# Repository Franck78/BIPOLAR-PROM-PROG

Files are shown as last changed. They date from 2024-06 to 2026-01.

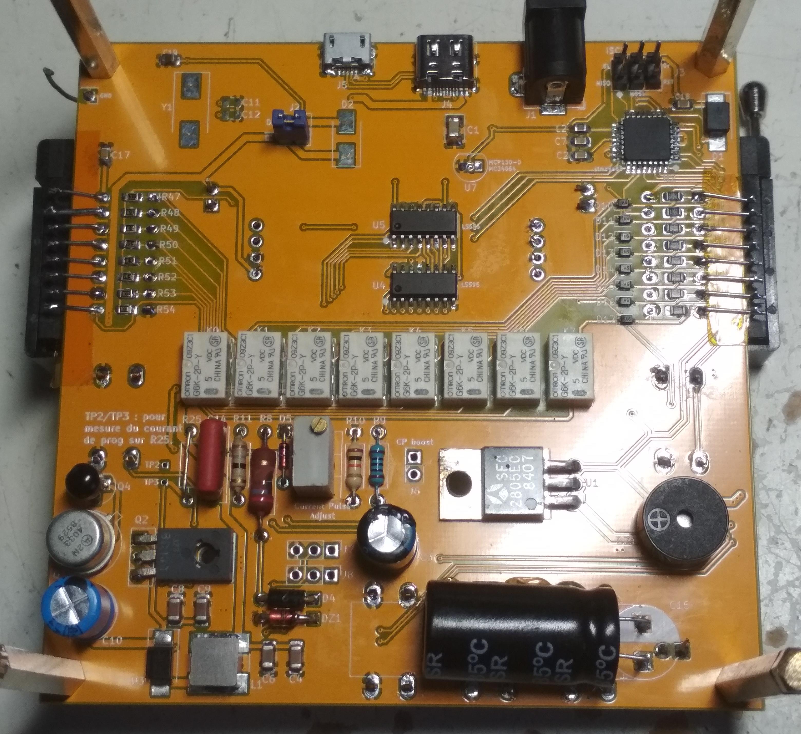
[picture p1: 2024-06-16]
images/assembled-bottom.jpg

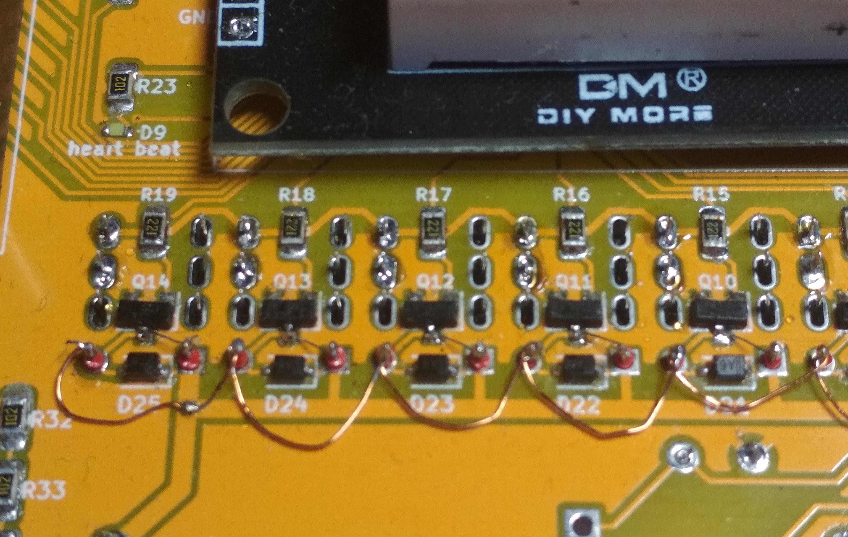
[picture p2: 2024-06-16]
images/relay-fix.jpg

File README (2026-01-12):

BIPOLAR PROM PROGRAMMER

Another one in the arena !

This one is based on the Atmega to repeat easily programming a PROM.

It reads the source from a master PROM
It writes what is memory to a virgin PROM

Values can be modified on the fly if needed. That is similar to
the 'manual' programmers found everywhere.

A default PROM file is used when 'Read' is pressed and nothing is in the socket.
The goal of this project was programming a dozen of PROMS, so it makes sense for me
to have that default loaded.

TODO: use the internal eeprom of the mega to store/retrieve PROM files. 
TODO: use the serial port to send files (remember entering 32 values is not really
time consumming, so this is luxury.

I'm using KiCad 5. It works for me until I upgrade my old laptop. Don't send request
about version.

The code is occupying 85% of the AtMega88. What is code consumming is
the human interface ! Moving to atMega328 is possible.
TODO: remove DigitalRead DigitalWrite functions (code consumming I think)

version 1.0 of the pcb was really botched to work. Version v1.1 fixed all that
but I made a mistake with the G6K relay footprint. In this repository, this is
fixed.
But I still have 4 usable PCB from JLCPCB. Pin 1 and 8 of each relay need to be
swapped. It can be done by soldering the relay on the other side. I choose to
put them on the correct side and inserted insulation on the two pins then solder
correctly.

Another thing is the ZIF socket. AliExpress 3M Textool is shit reproduction.
I ordered Aries reproduction, much better but pin space is 'wide'. But they
can be used. They can also be opened (a good hammer and strong pin) to 
reinsert each contact to get the narrow version.

HOW TO used

Insert the PROM to copy in the 'Read' socket, press 'R' button

The CRC32 is displayed until another key is pressed.
If all zero is read, then the default PROM file is used. 
This is signaled by a double beep.

Use + / - to display each address and content.
Press V to edit a value (with + / -). Display starts
blinking.
Press V again to accept the updated value.

When everything is OK, insert a virgin PROM and press 'W'
Program will fuse bit 0 on each 32 position, then bit 1
then ... This limits the relays actuating.

Read of the 'Write' socket is done for comparison. When
green LED lits, it is a success.
If not, retry. Only failed bits will be refused.

The serial port reports outputs what the programmer is doing.
Is is not required to have a terminal nut it helps.

I had in mind some flexibility for the current programming 
(the pulse). I did not explore possibilities of burning
other brand.
I have tested the programmer with

N82S23AN (K8608) from Signetics.
with minor modification and new software
TBP18S030N

I have 4 spare PCB to sell (instead of asking 5 new ones to JLPCB).
I'm not doing that for the money of course but avoid filling my bin.

About the PCB
I wanted sockets and button covered properly in a box. This why
all 'big' components are on the bottom side. 
Need to make a box now ;)

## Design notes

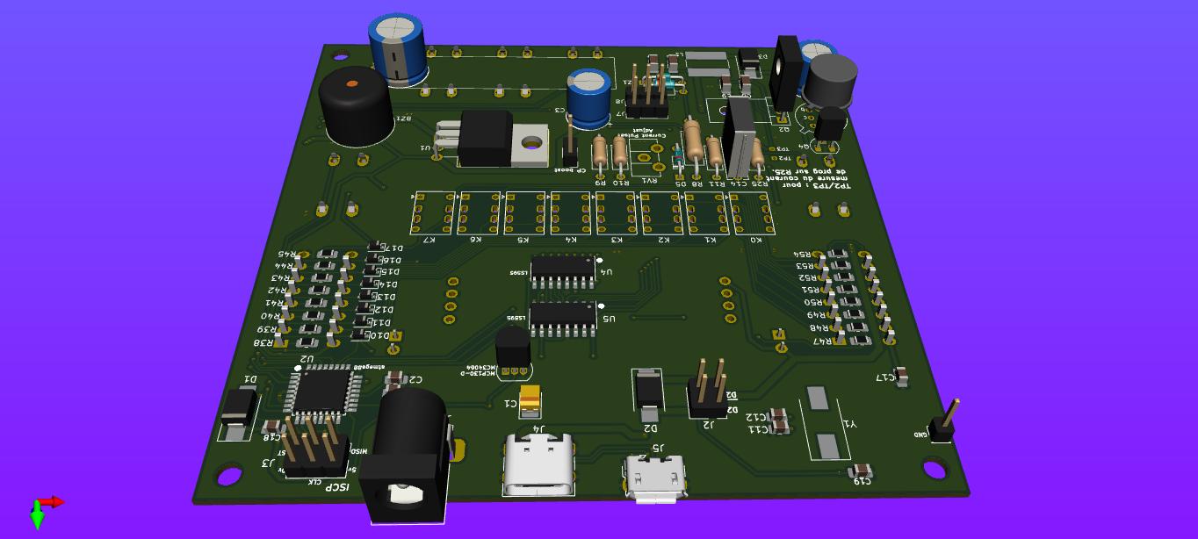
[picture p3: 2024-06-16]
images/kicad-prom-prog-bottom.jpg

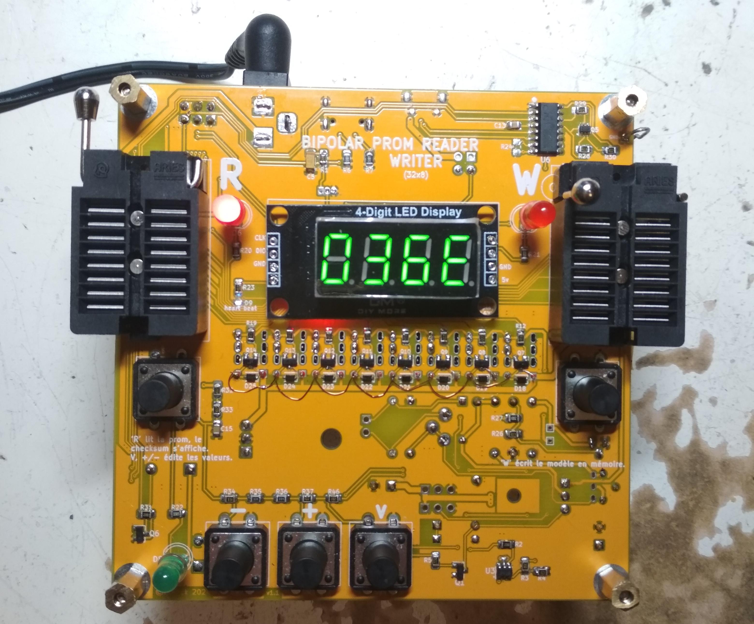
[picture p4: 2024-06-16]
images/running.jpg

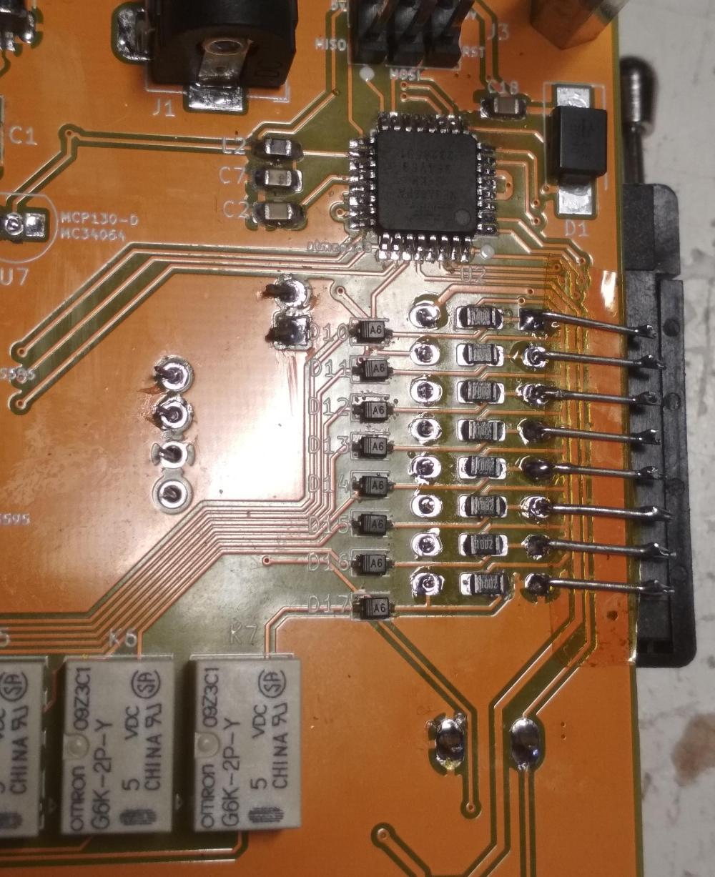
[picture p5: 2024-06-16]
images/using-aries-zif.jpg

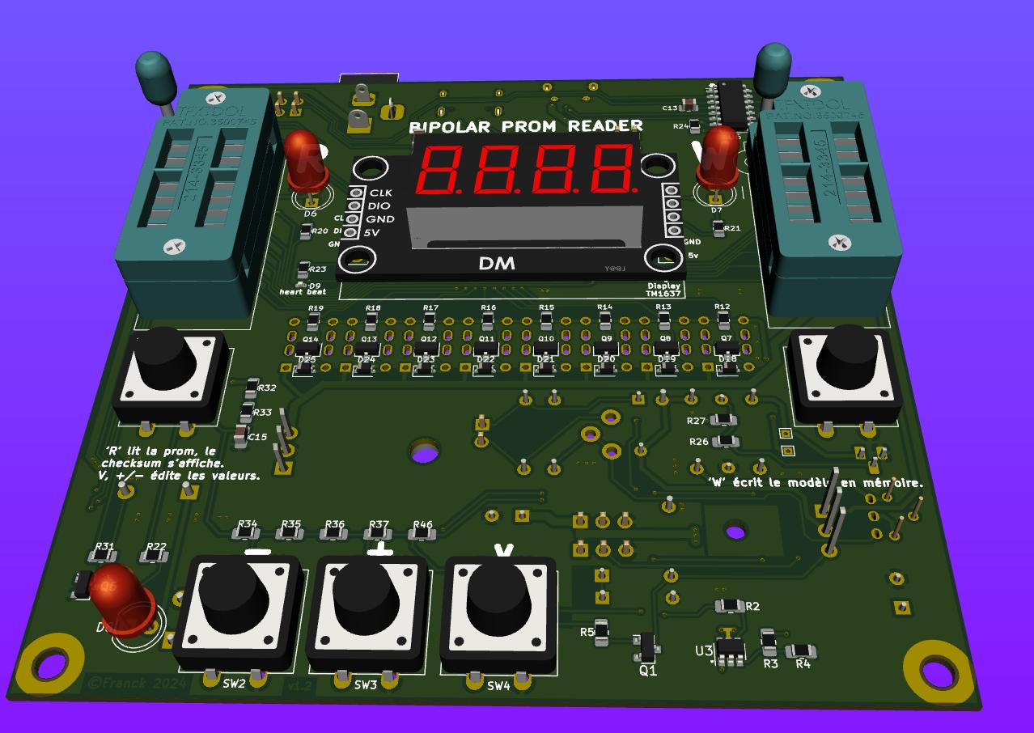
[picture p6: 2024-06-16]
images/kicad-prom-prog-top.jpg

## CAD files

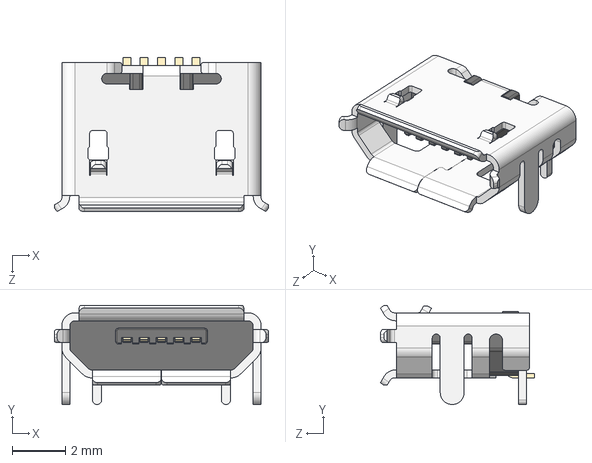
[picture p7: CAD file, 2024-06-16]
Micro USB-B Female 5Pin SMD.STEP
8.05 x 3.73 x 5.80 mm

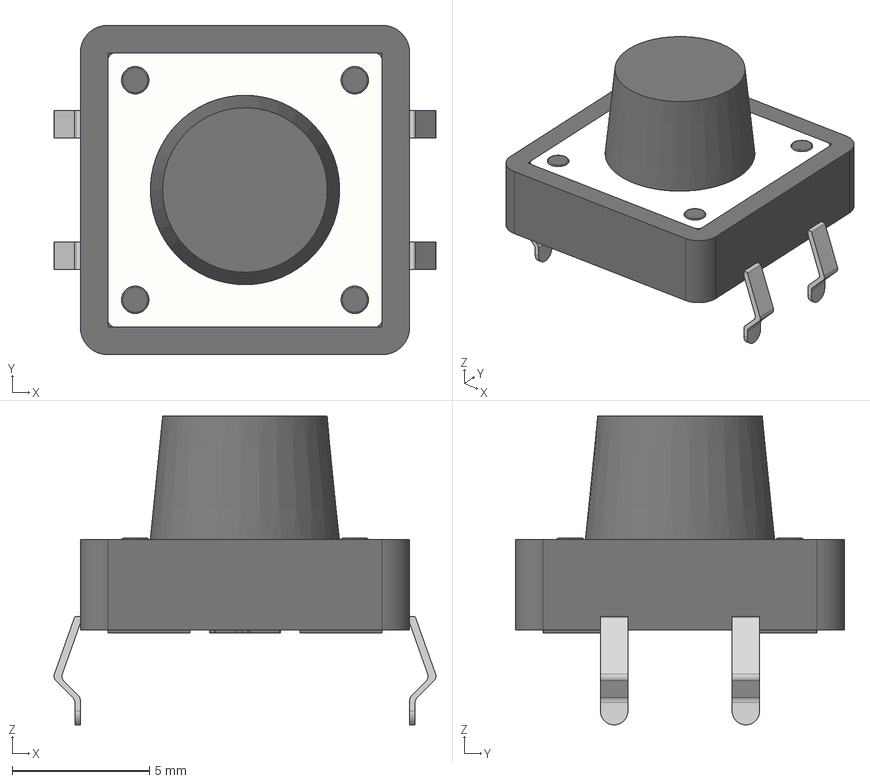
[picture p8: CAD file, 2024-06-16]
12mm x 12mm Tactile switch Button.step
13.9 x 12.0 x 11.2 mm
External Case
Steel Plate
Push Button

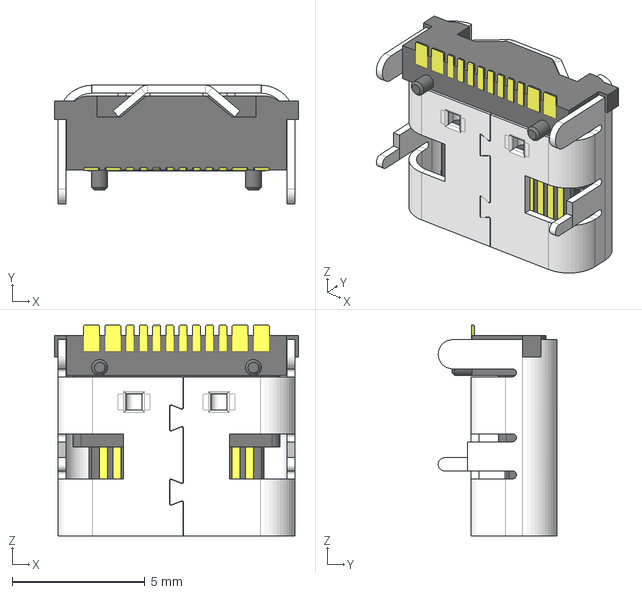
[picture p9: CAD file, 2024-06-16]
USB_type_C_smd_12p.stp
9.20 x 4.47 x 7.95 mm

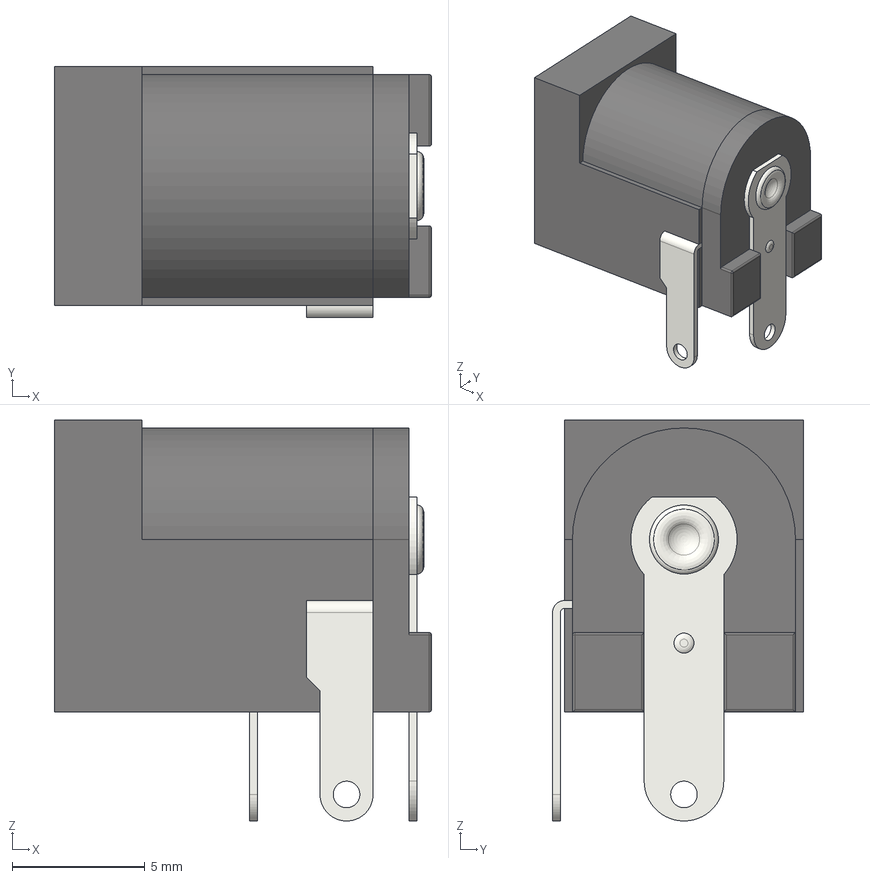
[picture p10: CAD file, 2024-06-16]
DC_Power_Jack_PCB_Mounted_2.1mm.step
14.2 x 9.45 x 15.1 mm
Plastic_Body_1of2
Plastic_Body_2of2
PIN_01
PIN_03
PIN_02
Boner

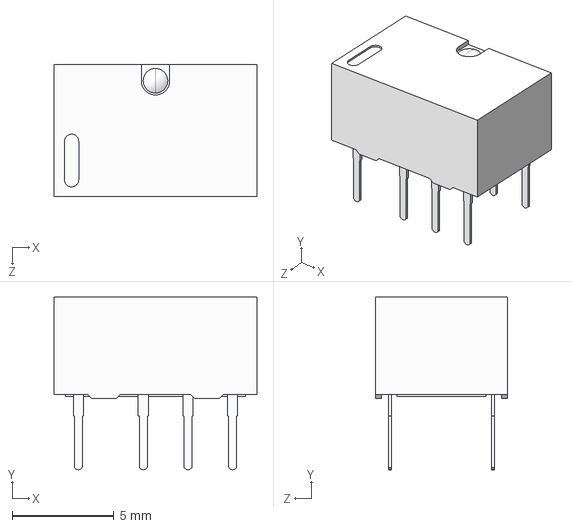
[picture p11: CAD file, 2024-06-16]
G6K-2P-Y-DC5.stp
10.0 x 8.50 x 6.50 mm

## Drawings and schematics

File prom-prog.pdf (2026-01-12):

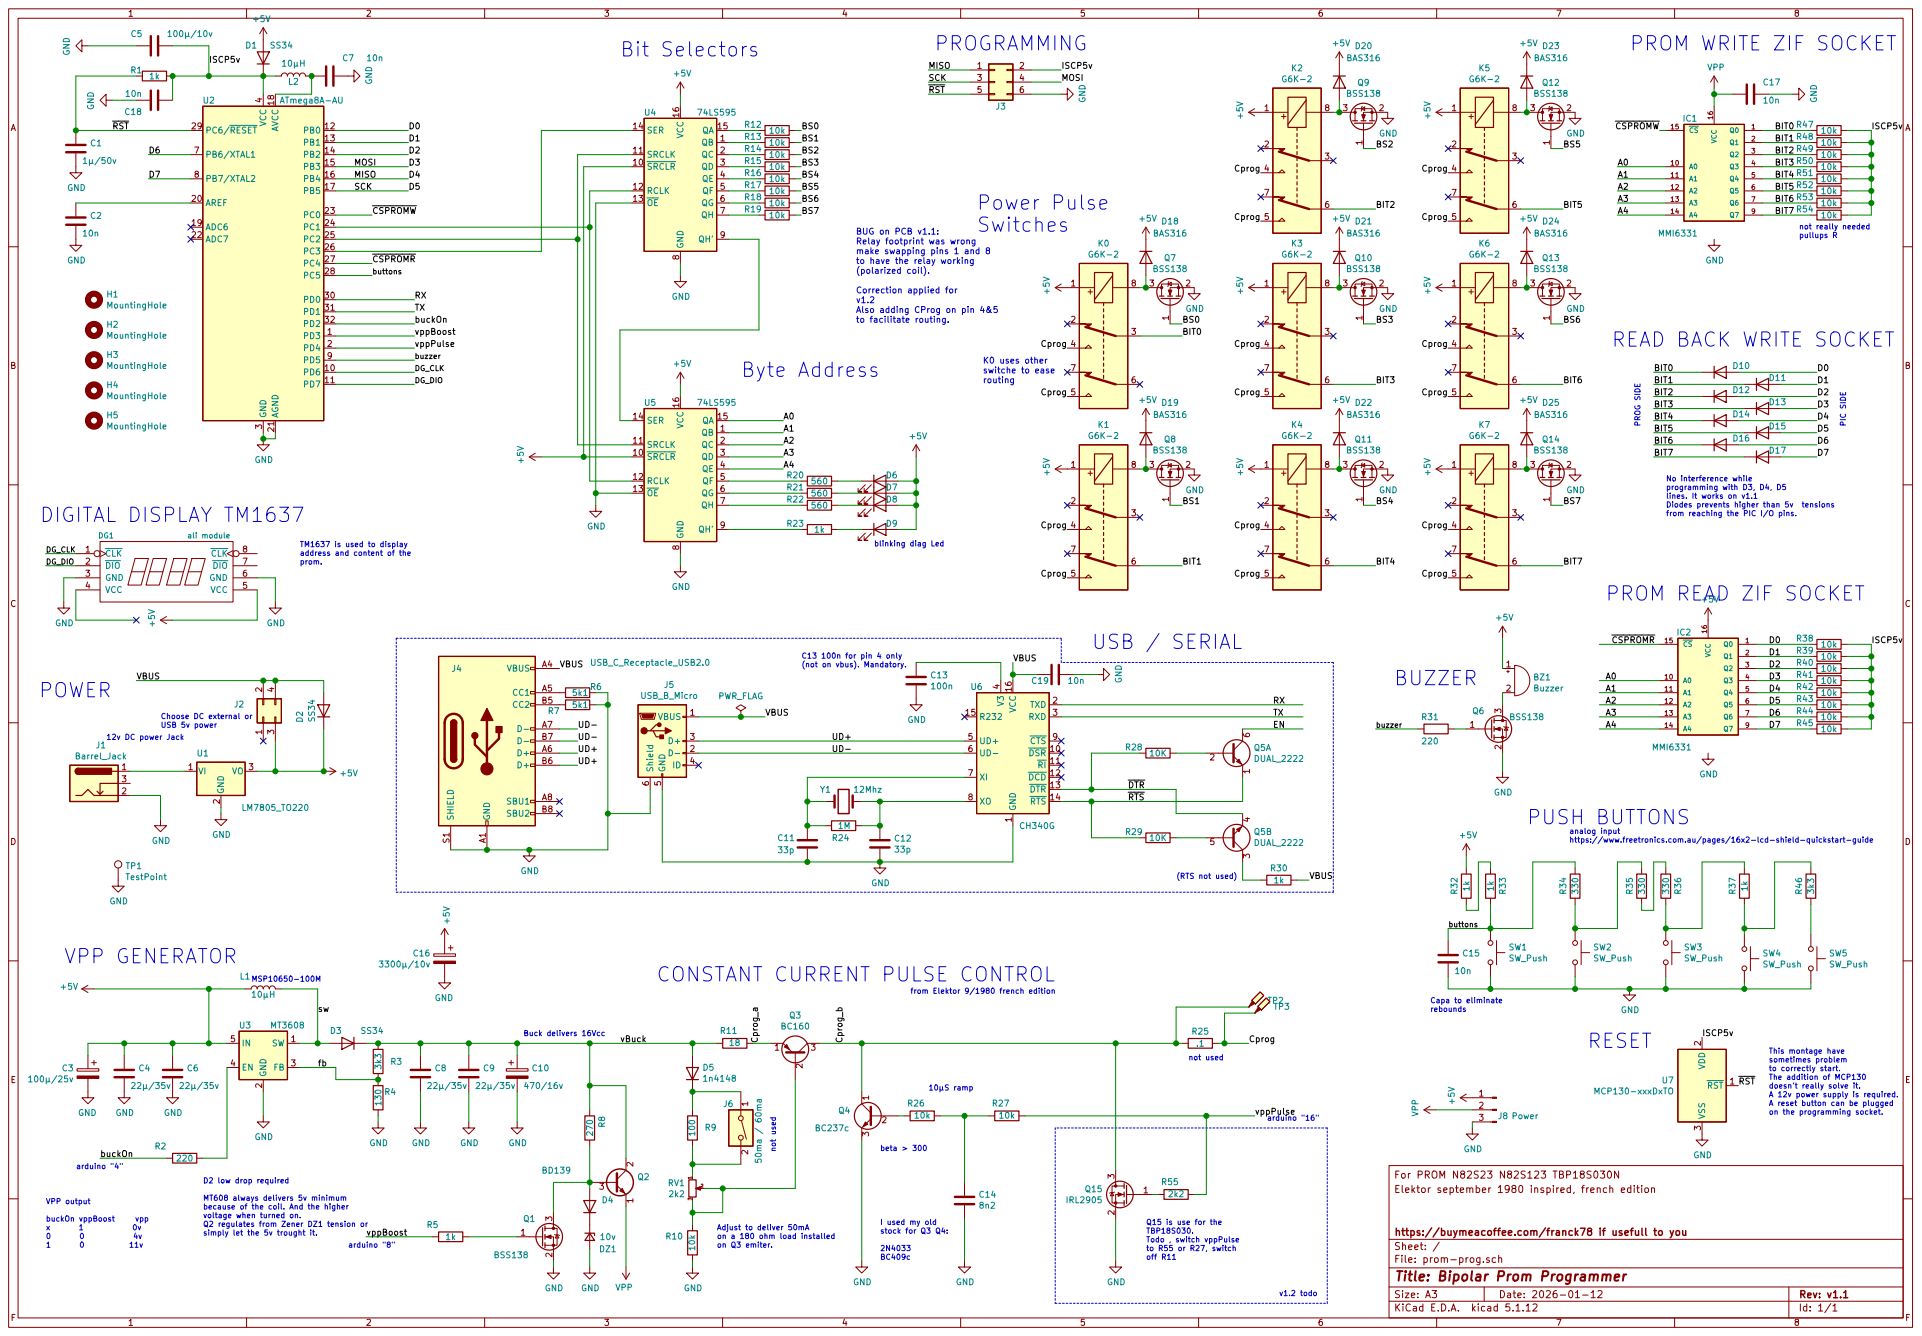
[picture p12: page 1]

(RTS not used) PROGRAMMING
Cprog SCK

PROM WRITE ZIF SOCKET

routing BUG on PCB v1.1: Relay footprint was wrong

make swapping pins 1 and 8
to have the relay working
(polarized coil).

Correction applied for v1.2 Also adding CProg on pin 4&5

READ BACK WRITE SOCKET

K0 uses other switche to ease

programming with D3, D4, D5
lines. It works on v1.1 Diodes prevents higher than 5v tensions

from reaching the PIC I/O pins. USB / SERIAL

TM1637 is used to display address and content of the

blinking diag Led
(not on vbus). Mandatory. not used

1 DSR 10 RI 11 DCD 12 DTR 13 RTS 14 R232 15 VCC 16 TXD 2 RXD 3 V3

4 UD+ 5 UD- 6 XI 7 XO 8 CTS 9 U6 CH340G VDD

analog input https://www.freetronics.com.au/pages/16x2-lcd-shield-quickstart-guide PUSH BUTTONS

rebounds CONSTANT CURRENT PULSE CONTROL

sometimes problem
to correctly start. The addition of MCP130

doesn't really solve it. A 12v power supply is required. A reset button can be plugged

on the programming socket. arduino "4"

D2 low drop required MT608 always delivers 5v minimum

Elektor september 1980 inspired, french edition For PROM N82S23 N82S123 TBP18S030N

because of the coil. And the higher voltage when turned on. Q2 regulates from Zener DZ1 tension or simply let the 5v trought it.

Adjust to deliver 50mA
on a 180 ohm load installed
on Q3 emiter.

Q15 is use for the TBP18S030. Todo , switch vppPulse

File: prom-prog.sch Sheet: / https://buymeacoffee.com/franck78 if usefull to you

Id: 1/1 Title: Bipolar Prom Programmer

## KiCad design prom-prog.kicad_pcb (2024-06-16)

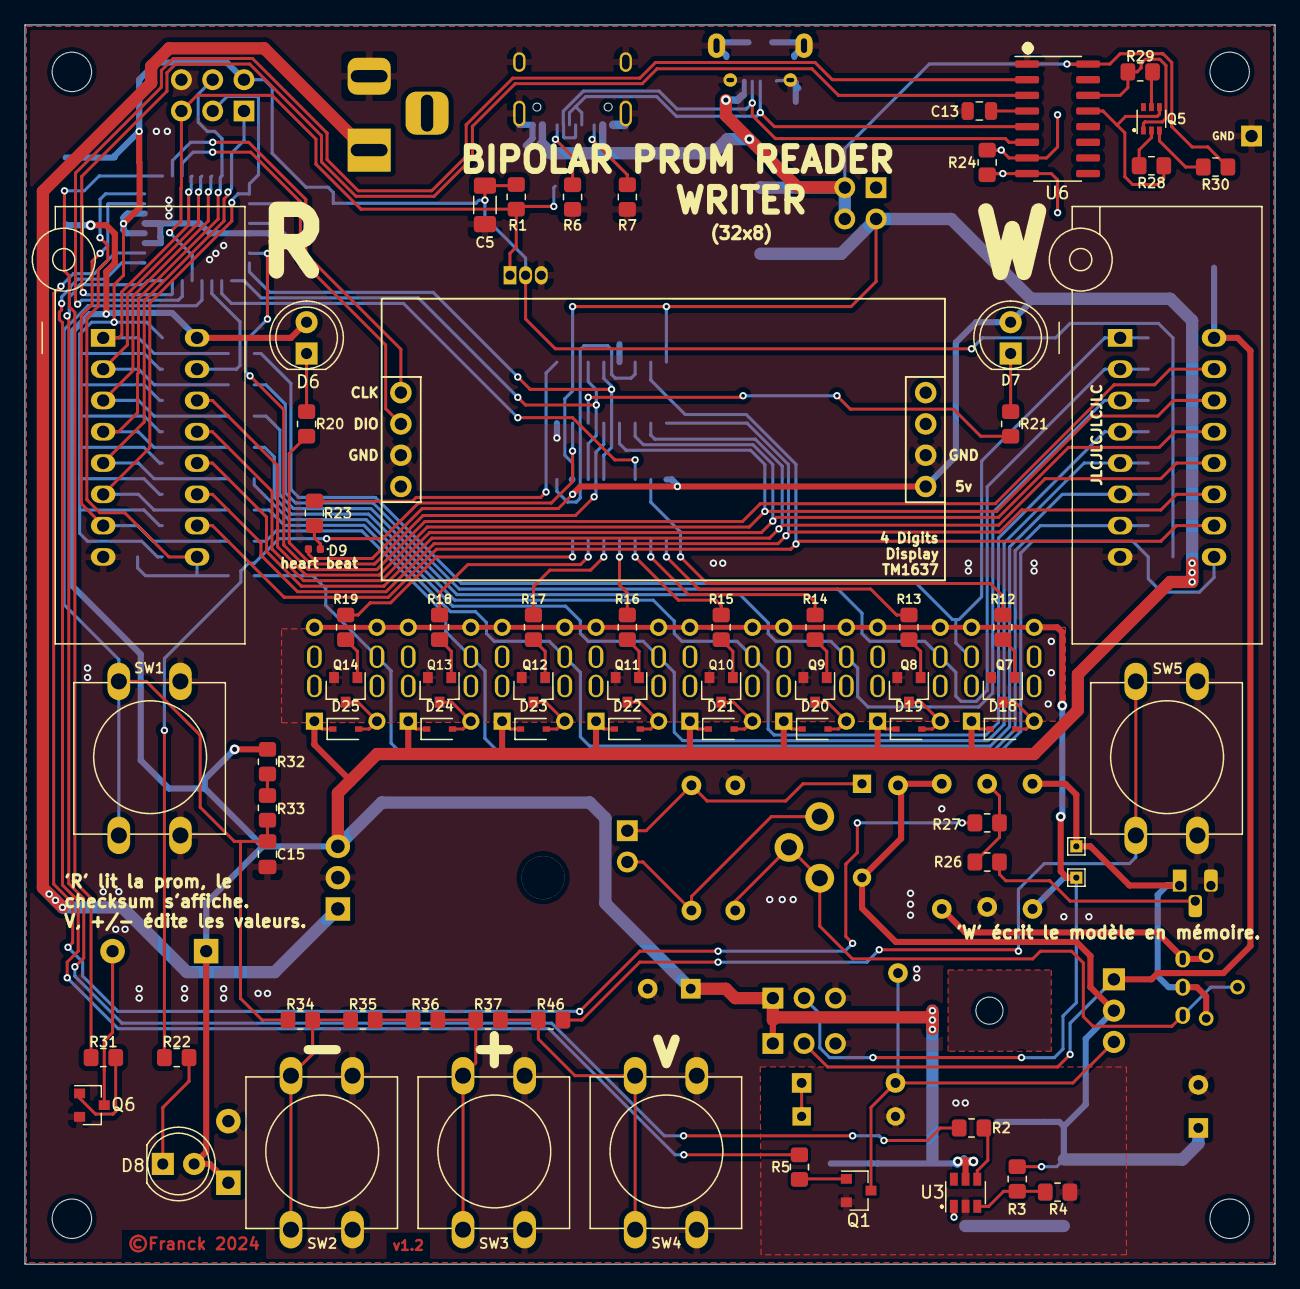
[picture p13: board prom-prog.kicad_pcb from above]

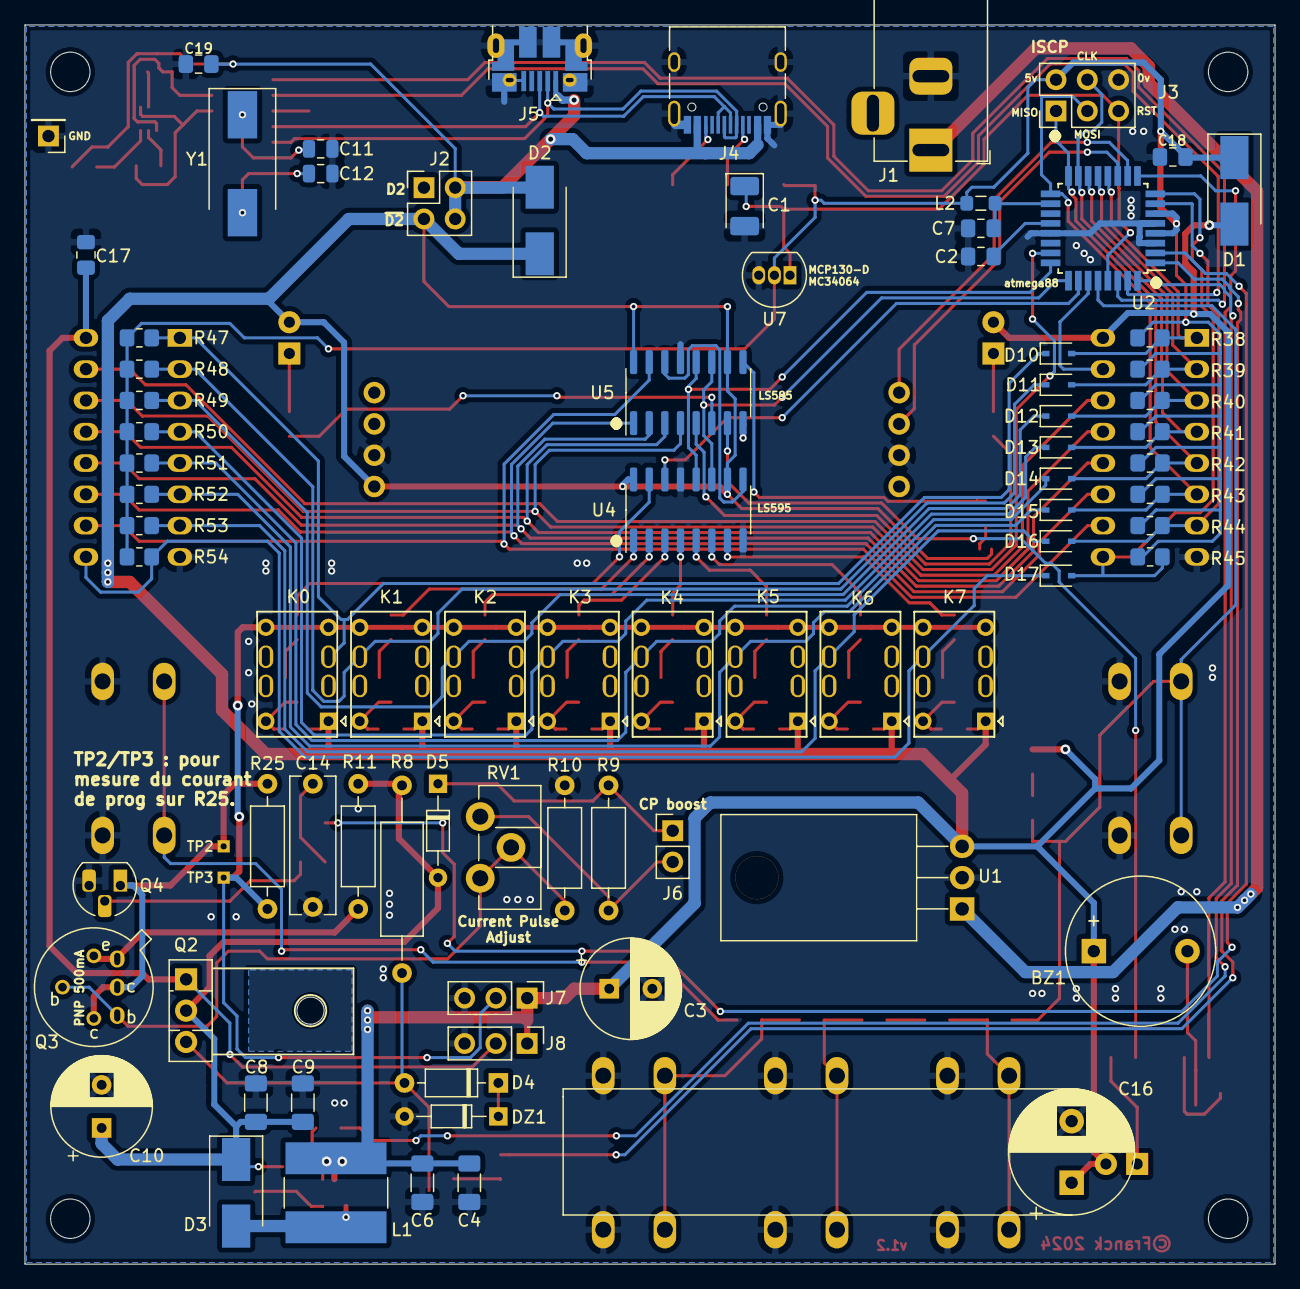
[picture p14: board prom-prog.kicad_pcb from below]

Board: 2 copper layers, 101.5 x 100.6 mm, 157 parts (81 on the bottom side), 112 nets.

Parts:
BZ1: Buzzer; Buzzer_12x9.5RM7.6
C1: 1µ/50v; CP_EIA-3528-21_Kemet-B_Pad1.50x2.35mm_HandSolder
C2, C7, C15, C17, C18, C19: 10n; C_0805_2012Metric_Pad1.18x1.45mm_HandSolder
C3: 100µ/25v; CP_Radial_D8.0mm_P3.50mm
C4, C6, C8, C9: 22µ/35v; C_1206_3216Metric_Pad1.33x1.80mm_HandSolder
C5: 100µ/10v; C_1206_3216Metric_Pad1.33x1.80mm_HandSolder
C10: 470/16v; CP_Radial_D8.0mm_P3.50mm
C11, C12: 33p; C_0805_2012Metric
C13: 100n; C_0805_2012Metric
C14: 8n2; C_Rect_L11.0mm_W3.5mm_P10.00mm_MKT
C16: 3300µ/10v; CP_Radial_D10.0mm_P5.00mm
D1, D2, D3: SS34; D_SMB_Handsoldering
D4: 1n4004; D_DO-35_SOD27_P7.62mm_Horizontal
D5: 1n4148; D_DO-34_SOD68_P7.62mm_Horizontal
D6, D7, D8: LED; LED_D5.0mm
D9: LED; LED_0402_1005Metric
D10, D11, D12, D13, D14, D15, D16, D17: 1n4148; D_SOD-323
D18, D19, D20, D21, D22, D23, D24, D25: BAS316; D_SOD-323
DG1: ali module; 4DigitSerial
DZ1: 10v; D_DO-34_SOD68_P7.62mm_Horizontal
H1, H2, H3, H4: MountingHole; MountingHole_3.2mm_M3
H5: MountingHole; MountingHole_2.2mm_M2_DIN965
IC1, IC2: MMI6331; DIP_Socket-16_W4.3_W5.08_W7.62_W10.16_W10.9_3M_216-3340-00-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
J1: Barrel_Jack; BarrelJack_Horizontal
J2: Conn_02x02_Odd_Even; PinHeader_2x02_P2.54mm_Vertical
J3: Conn_02x03_Odd_Even; PinHeader_2x03_P2.54mm_Vertical
J4: USB_C_Receptacle_USB2.0; USB_C_Receptacle_HRO_TYPE-C-31-M-12
J5: USB_B_Micro; USB_Micro-B_AliExpress
J6: 50ma / 60ma; PinHeader_1x02_P2.54mm_Vertical
J7, J8: Power; PinHeader_1x03_P2.54mm_Vertical
K0, K1, K2, K3, K4, K5, K6, K7: G6K-2; G6K-2P-YZ
L1: 10µH; L_Bourns-SRN8040_8x8.15mm
L2: 10µH; L_0805_2012Metric_Pad1.05x1.20mm_HandSolder
Q1, Q6, Q7, Q8, Q9, Q10, Q11, Q12, Q13, Q14: BSS138; SOT-23
Q2: BD139; TO-126-3_Vertical
Q3: BC160; TO-39-3
Q4: BC237; TO-92_HandSolder
Q5: DUAL_2222; SOT-363_SC-70-6
R1, R5, R23, R30, R32, R33, R37: 1k; R_0805_2012Metric_Pad1.20x1.40mm_HandSolder
R2, R31: 220; R_0805_2012Metric_Pad1.20x1.40mm_HandSolder
R3, R46: 3k3; R_0805_2012Metric_Pad1.20x1.40mm_HandSolder
R4: 130; R_0805_2012Metric_Pad1.20x1.40mm_HandSolder
R6, R7: 5k1; R_0805_2012Metric_Pad1.20x1.40mm_HandSolder
R8: 270; R_Axial_DIN0309_L9.0mm_D3.2mm_P15.24mm_Horizontal
R9: 100; R_Axial_DIN0207_L6.3mm_D2.5mm_P10.16mm_Horizontal
R10: 10k; R_Axial_DIN0207_L6.3mm_D2.5mm_P10.16mm_Horizontal
R11: 18; R_Axial_DIN0207_L6.3mm_D2.5mm_P10.16mm_Horizontal
R12, R13, R14, R15, R16, R17, R18, R19, R26, R27, R38, R39, R40, R41, R42, R43, R44, R45, R47, R48, R49, R50, R51, R52, R53, R54: 10k; R_0805_2012Metric_Pad1.20x1.40mm_HandSolder
R20, R21, R22: 560; R_0805_2012Metric_Pad1.20x1.40mm_HandSolder
R24: 1M; R_0805_2012Metric_Pad1.20x1.40mm_HandSolder
R25: .1; R_Axial_DIN0207_L6.3mm_D2.5mm_P10.16mm_Horizontal
R28, R29: 10K; R_0805_2012Metric_Pad1.20x1.40mm_HandSolder
R34, R35, R36: 330; R_0805_2012Metric_Pad1.20x1.40mm_HandSolder
RV1: 2k2; Potentiometer_ACP_CA9-H2,5_Horizontal
SW1, SW2, SW3, SW4, SW5: SW_Push; SW_PUSH-12mm
TP1: TestPoint; PinHeader_1x01_P2.54mm_Vertical
TP2, TP3: TestPoint_Probe; TestPoint_THTPad_1.0x1.0mm_Drill0.5mm
U1: LM7805_TO220; TO-220-3_Horizontal_TabDown
U2: ATmega8A-AU; TQFP-32_7x7mm_P0.8mm
U3: MT3608; SOT-23-6
U4, U5: 74LS595; SOIC-16_3.9x9.9mm_P1.27mm
U6: CH340G; SOIC-16_3.9x9.9mm_P1.27mm
U7: MCP130-xxxDxTO; TO-92_Inline
Y1: 12Mhz; Crystal_SMD_EuroQuartz_MQ2-2Pin_7.0x5.0mm_HandSoldering

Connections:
+5V: BZ1.1, C3.1, C4.1, C6.1, C16.1, D1.2, D2.1, D6.2, D7.2, D8.2, D9.2, D18.1, D19.1, D20.1, D21.1, D22.1, D23.1, D24.1, D25.1, DG1.5, IC2.16, J2.3, J7.1, J8.1, K0.1, K1.1, K2.1, K3.1, K4.1, K5.1, K6.1, K7.1, L1.1, R32.1, U1.3, U3.5, U4.10, U4.16, U5.10, U5.16
/A0: IC1.10, IC2.10, U5.15
/A1: IC1.11, IC2.11, U5.1
/A2: IC1.12, IC2.12, U5.2
/A3: IC1.13, IC2.13, U5.3
/A4: IC1.14, IC2.14, U5.4
/BIT0: D10.1, IC1.1, K0.3, R47.2
/BIT1: D11.1, IC1.2, K1.6, R48.2
/BIT2: D12.1, IC1.3, K2.6, R49.2
/BIT3: D13.1, IC1.4, K3.6, R50.2
/BIT4: D14.1, IC1.5, K4.6, R51.2
/BIT5: D15.1, IC1.6, K5.6, R52.2
/BIT6: D16.1, IC1.7, K6.6, R53.2
/BIT7: D17.1, IC1.9, K7.6, R54.2
/BS0: Q7.1, R12.1
/BS1: Q8.1, R13.1
/BS2: Q9.1, R14.1
/BS3: Q10.1, R15.1
/BS4: Q11.1, R16.1
/BS5: Q12.1, R17.1
/BS6: Q13.1, R18.1
/BS7: Q14.1, R19.1
/Cprog: J7.2, K0.4, K0.5, K1.4, K1.5, K2.4, K2.5, K3.4, K3.5, K4.4, K4.5, K5.4, K5.5, K6.4, K6.5, K7.4, K7.5, R25.1, TP3.1
/Cprog_a: Q3.1, R11.2
/Cprog_b: Q3.3, Q4.1, R25.2, TP2.1
/D0: D10.2, IC2.1, R38.2, U2.12
/D1: D11.2, IC2.2, R39.2, U2.13
/D2: D12.2, IC2.3, R40.2, U2.14
/D3: D13.2, IC2.4, J3.4, R41.2, U2.15
/D4: D14.2, IC2.5, J3.1, R42.2, U2.16
/D5: D15.2, IC2.6, J3.3, R43.2, U2.17
/D6: D16.2, IC2.7, R44.2, U2.7
/D7: D17.2, IC2.9, R45.2, U2.8
/DG_CLK: DG1.1, U2.10
/DG_DIO: DG1.2, U2.11
/ISCP5v: C5.1, C18.2, D1.1, J3.2, L2.1, R1.1, R38.1, R39.1, R40.1, R41.1, R42.1, R43.1, R44.1, R45.1, R47.1, R48.1, R49.1, R50.1, R51.1, R52.1, R53.1, R54.1, U2.4, U2.6, U7.2
/RX: U2.30, U6.2
/TX: U2.31, U6.3
/UD+: J4.A6, J4.B6, J5.3, U6.5
/UD-: J4.A7, J4.B7, J5.2, U6.6
/VBUS: C19.2, D2.2, J2.2, J2.4, J4.A4, J4.A9, J4.B4, J4.B9, J5.1, R30.1, U6.16
/buckOn: R2.2, U2.32
/buttons: C15.1, R33.2, R34.1, SW1.1, U2.28
/buzzer: R31.2, U2.9
/fb: R3.2, R4.1, U3.3
/sw: D3.2, L1.2, U3.1
/vBuck: C8.1, C9.1, C10.1, D3.1, D5.2, Q2.2, R3.1, R8.1, R11.1
/vppBoost: R5.2, U2.1
/vppPulse: R27.2, U2.2
/~CSPROMR~: IC2.15, U2.27
/~CSPROMW~: IC1.15, U2.23
/~DTR: Q5.4, R28.2, U6.13
/~RST: C1.1, J3.5, R1.2, U2.29, U7.1
/~RTS: Q5.1, R29.2, U6.14
GND: C1.2, C2.2, C3.2, C4.2, C5.2, C6.2, C7.1, C8.2, C9.2, C10.2, C11.2, C12.2, C13.2, C14.1, C15.2, C16.2, C17.1, C18.1, C19.1, DG1.3, DG1.6, DZ1.2, IC1.8, IC2.8, J1.2, J3.6, J4.A1, J4.A12, J4.B1, J4.B12, J4.S1, J5.5, J5.6, J7.3, J8.3, Q1.2, Q4.3, Q6.2, Q7.2, Q8.2, Q9.2, Q10.2, Q11.2, Q12.2, Q13.2, Q14.2, R4.2, R6.1, R7.1, R10.1, SW1.2, SW2.2, SW3.2, SW4.2, SW5.2, TP1.1, U1.2, U2.3, U2.5, U2.21, U3.2, U4.8, U4.13, U5.8, U5.13, U6.1, U7.3
unnamed: BZ1.2, Q6.3
unnamed: C2.1, U2.20
unnamed: C7.2, L2.2, U2.18
unnamed: C11.1, R24.2, U6.7, Y1.1
unnamed: C12.1, R24.1, U6.8, Y1.2
unnamed: C13.1, U6.4
unnamed: C14.2, R26.2, R27.1
unnamed: D4.1, DZ1.1
unnamed: D4.2, Q1.3, Q2.3, R8.2
unnamed: D5.1, J6.1, R9.2
unnamed: D6.1, R20.1
unnamed: D7.1, R21.1
unnamed: D8.1, R22.1
unnamed: D9.1, R23.1
unnamed: D18.2, K0.8, Q7.3
unnamed: D19.2, K1.8, Q8.3
unnamed: D20.2, K2.8, Q9.3
unnamed: D21.2, K3.8, Q10.3
unnamed: D22.2, K4.8, Q11.3
unnamed: D23.2, K5.8, Q12.3
unnamed: D24.2, K6.8, Q13.3
unnamed: D25.2, K7.8, Q14.3
unnamed: J1.1, U1.1
unnamed: J4.A5, R6.2
unnamed: J4.B5, R7.2
unnamed: J6.2, R9.1, RV1.1
unnamed: Q1.1, R5.1
unnamed: Q3.2, R10.2, RV1.2, RV1.3
unnamed: Q4.2, R26.1
unnamed: Q5.2, R28.1
unnamed: Q5.3, R30.2
unnamed: Q5.5, R29.1
unnamed: Q6.1, R31.1
unnamed: R2.1, U3.4
unnamed: R12.2, U4.15
unnamed: R13.2, U4.1
unnamed: R14.2, U4.2
unnamed: R15.2, U4.3
unnamed: R16.2, U4.4
unnamed: R17.2, U4.5
unnamed: R18.2, U4.6
unnamed: R19.2, U4.7
unnamed: R20.2, U5.5
unnamed: R21.2, U5.6
unnamed: R22.2, U5.7
unnamed: R23.2, U5.9
unnamed: R32.2, R33.1
unnamed: R34.2, R35.1, SW2.1
unnamed: R35.2, R36.1
unnamed: R36.2, R37.1, SW3.1
unnamed: R37.2, R46.1, SW4.1
unnamed: R46.2, SW5.1
unnamed: U2.24, U4.12, U5.12
unnamed: U2.25, U4.11, U5.11
unnamed: U2.26, U4.14
unnamed: U4.9, U5.14
VPP: C17.2, IC1.16, J8.2, Q2.1

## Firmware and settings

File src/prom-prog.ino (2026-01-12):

/*
 * 
 *     Arduino IDE setup:
 *
 *  add in boards.txt file something describing the ATMEGA88P  (P is important)
 *  Any megaxx8 should be ok.
 *


## Arduino Pro or Pro Mini (5V, 8 MHz) w/ ATmega88
## -------------------------------------------------
pro.menu.cpu.8MHzatmega88=ATmega88P (5V, 8 MHz no crystal)

pro.menu.cpu.8MHzatmega88.upload.maximum_size=8000
pro.menu.cpu.8MHzatmega88.upload.maximum_data_size=1024
pro.menu.cpu.8MHzatmega88.upload.speed=19200

pro.menu.cpu.8MHzatmega88.build.mcu=atmega88p
pro.menu.cpu.8MHzatmega88.build.f_cpu=8000000L
pro.menu.cpu.8MHzatmega88.bootloader.low_fuses=0xc2
pro.menu.cpu.8MHzatmega88.bootloader.high_fuses=0xdf
pro.menu.cpu.8MHzatmega88.bootloader.extended_fuses=0x01


 * IDE Settings
 *
 * Board     : Arduino Promini
 * Processor : ATmega88P
 * Progammer : USBASP
 *       
 *        
 * Hardware description:
 * 
 * The 16 bits shift registers (two classic 74595) control the hardware
 * --1 of 8 bits to be fused via mini relay
 * --5 bits for prom address
 * --LED1 (red)
 * --LED2 (red)
 * --LED3 (green)
 * 
 * Ports usage on Mega88P
 * 
 * PromR => prom read socket
 * PromW => prom write socket
 * 
 * PORTB 8 bits data bus from PromR and PromW
 * 
 * PC0 CSPROMW
 * PC1 HC595 latch rclk
 * PC2 HC595 serial clock
 * PC3 HC595 serial data
 * PC4 CSPROMR 
 * 
 * PC5 analogic buttons chain input
 * PC6 reset
 * PC7 nc
 * 
 * PD0 CH340 RX to USB
 * PD1 CH340 TX to USB
 * PD2 buckOn enable buck MT3608
 * PD3 vppBoost enable VPP or 5v
 * PD4 vppPulse pulseEnable
 * 
 * PD5 Buzzer
 * PD6_DG_CLK
 * PD7 DG_DIO (TM1637 4 digit display)
 *
 *
 * The burning generator hardware is based on Elektor september 1980 (french edition) prom programmer
 * 
 */


#ifdef __AVR_ATmega8__
#define VERSION "v2.0 ATmega8"
#else
#define VERSION "v2.0 ATmega88P"
#endif


/*
 * #define TEST
 * switche code for testing the programming of a new chip
 * -focuse on repeating a single bit of the inserted prom
 * 
 */
//#define TEST

/*
 * These are used for individual bit burning tests ;)
 *
 * bad TBP18S
 * FF FF FF FF FF FF FF 7F A4 D0 E8 AD 3F 06 FF 40 1F 05 04 02 98 37 AA AC 16 AE 24 11 52 A4 F6 FF
 * 
 * bad N82S23
 * 80 A0 5B 4F 66 6D 7D 07 7F 6F 81 79 38 3E 1E 00 3F 06 5B 4F 66 ED 7D 07 7F 6F 81 79 38 3E 1E BF
 * 
 */



#include <avr/wdt.h> // watchdog

/* Some code remaining from another app, not used yet. 
 *
 * Todo (on 328) : store / select prom files in eeprom.
 * It is the human interface that is requiring lot of code.
 * I don't think the Mega88 have enougth code space.
 * Todo : use serial port to tranfert prom files
 *
 */
#include <EEPROM.h>  // for nvram


/*
 *  The 4 digits (aliexpress TM1637) is used to display
 *  the prom address (0..31) and its content.
 *  The buttons allow editing values. When in edit mode
 *  the value is blinking. To make this visually good
 *  canBlink, canBlink2 force visibility during this
 *  blinkState mode.
 *  As I chose interrupt every millisecond to update display
 *  the 'effective' call to the chip TM1637 must be made only 
 *  when a change has occured. This makes the display update 
 *  a little tricky, and more tricky when blinking 2 digits !
 *  
 */
#include "TM1637Display.h"


#define tm1637_c      PD6
#define tm1637_d      PD7
#define buzzer        PD5
TM1637Display         Info(tm1637_c,tm1637_d);
boolean               blinkState;
boolean               canBlink, canBlink2;
byte                  digits [4];
byte                  digitsB [4] = {0,0,0,0}; // blinking version

/*
 *  The crc is displayed just after reading until a button is pressed
 */
byte                  displayCrc = 0;  // mini state machine, displays high or low part or nothing
unsigned long         crc;

#define HC595         PORTC
#define HC595_SER     PC3
#define HC595_RCLK    PC1
#define HC595_SRCLK   PC2

#define CLR(x,y)  (x&=(~(1<<y)))
#define SET(x,y)  (x|=(1<<y))
#define _BV(bitN) (1 << (bitN))

//#define SetHC595_RCLK(bitval)  ((bitval>0) ? (SET(HC595,2)) : (CLR(HC595,2)))
//#define SetHC595_SRCLK(bitval) ((bitval>0) ? (SET(HC595,3)) : (CLR(HC595,3)))
//#define SetHC595_SER(bitval)   ((bitval>0) ? (SET(HC595,4)) : (CLR(HC595,4)))





/*
 * Data shifted out
 */
#define        HC595_REG_lamp   0
#define        HC595_REG_bitsel 1
volatile byte  HC595_REGS[2]; 

/* 
 *  
 * ls595 U5 controls Prom Address and LEDs
 * 
 */
#define setPromAddr(v) ( HC595_REGS[HC595_REG_lamp] = ( (HC595_REGS[HC595_REG_lamp] & 0B11100000) | (v & 0B00011111) ) )
#define setLedR(bitval) ((bitval>0) ? (SET(HC595_REGS[HC595_REG_lamp],5)) : (CLR(HC595_REGS[HC595_REG_lamp],5)))
#define setLedW(bitval) ((bitval>0) ? (SET(HC595_REGS[HC595_REG_lamp],6)) : (CLR(HC595_REGS[HC595_REG_lamp],6)))
#define  setLed(bitval) ((bitval>0) ? (SET(HC595_REGS[HC595_REG_lamp],7)) : (CLR(HC595_REGS[HC595_REG_lamp],7)))

/*  
 * U4 selects the bit colums to be programmed. The delay let IRQ propagate to the ls595
 * Basically turn on the relay to connect the data line of the prom to the correct
 * voltage generator
 */
#define setPromBitSelector(v) ( HC595_REGS[HC595_REG_bitsel] = _BV(v & 0B00000111) ); \
        delay (3)
#define clearPromBitSelector ( HC595_REGS[HC595_REG_bitsel] = 0 ); \
        delay (3)

// buckOn, vppBoost, vppPulse
// do not use digitalWrite
#define buckOn      4   /*(PD2)*/
#define vppNoBoost  8   /*(PD3)*/
#define vppQ4      16   /*(PD4)*/

/* 
 * more expressive macro , 
 * noZero means Q4 is open for the TBP18S030 
 * noPulse means Q4 is closed for the N82S23
 */
#define VPP0V_Q4open    (0      + vppNoBoost        )
#define VPP0V_Q4closed  (0      + vppNoBoost + vppQ4) 
#define VPP5V_Q4open    (0                          )
#define VPP5V_Q4closed  (0                   + vppQ4)
#define VPP10V_Q4open   (buckOn                     )
#define VPP10V_Q4closed (buckOn              + vppQ4)


/*
 * BUTTONS
 * The programm ask the button function the state and is replied some kinf of message.
 * For eliminating rebounds (I didn't check if really necessary), it was quick
 * fixes to what seemed strange behavior of press/depress vs time response.
 * 
 */

#define AnalogButtons (PC5)
enum buttonsMessage   { btNone, btRead, btMoins, btPlus, btVal, btWrite, btReadRel, btMoinsRel, btPlusRel, btValRel, btWriteRel };
volatile unsigned int countDown;
volatile byte         countDownRebound;
unsigned int          repeatSpeed = 300;
boolean               btInRepeat = false;
buttonsMessage        lastBt = btNone;
int                   lastButtonVoltage = -1;

/* 
 *  Prom Chip Selects pins (CS)
 *
 * For some reason, using DigitalWrite with PC1 PC3 is not working
 * Also, they are code bytes consuming !
 * So, directly set bits
 * Disable interrupt because is would kill ls595 IRQ controling !
 * Todo: inline assembler sbi/cbi to remove noInterrupts()
 * 
 */
#define promReadCS0         \
    noInterrupts();         \
    PORTC = 0b11101111 ;    \
    interrupts()

#define promReadCS1         \
    noInterrupts();         \
    PORTC = 255;            \
    interrupts()

#define promWriteCS0        \
    noInterrupts();         \
    PORTC = 0b11111110;     \
    interrupts()

#define promWriteCS1        \
    noInterrupts();         \
    PORTC = 255;            \
    interrupts()


//Working Data

byte    promReadData [32];
byte    promAddress;
byte    promWriteData [32];
boolean promReadEditData = false;
boolean promReadEmpty = true;

/*
 *
 * This is the default PROM file used when Read is pressed without chip inserted. 
 * A double bip is emitted when this file is used.
 * The first goal of this project was Jeutel pinball display drivers on A1 board.
 * 
 */
byte jeutel [32] = { 0x3f, 0x80, 0x5b, 0x4f,  0x66, 0x6d, 0x7d, 0x07,  0x7f, 0x6f, 0x81, 0x79,  0x38, 0x3e, 0x1e, 0x00,
                     0x3f, 0x06, 0x5b, 0x4f,  0x66, 0x6d, 0x7d, 0x07,  0x7f, 0x6f, 0x81, 0x79,  0x38, 0x3e, 0x1e, 0x00 };


byte gberet [32] = { 0x00, 0x1A, 0x26, 0x1C,  0xB6, 0x74, 0x0A, 0x52,  0xA4, 0xD0, 0xE8, 0xAD,  0x3F, 0x06, 0xFF, 0x40,
                     0x00, 0x05, 0x04, 0x02,  0x88, 0x37, 0xAA, 0xAC,  0x16, 0xAE, 0x24, 0x10,  0x52, 0xA4, 0xF6, 0xFF };

/*
 * NOT USED YET
 * Data in this structure are written to the eeprom
 * 
 * for now, this is unused. the eeprom could store lot of 32 bits bipolars but
 * it requires lot of programming to manage / choose and mega88 is full.
 * 
 */
 struct t_nvram {

  byte cm_okflg = 0x55;

} ;


class NvRam {
  public:
  t_nvram  d; //data
  void Init()
  {
      //Read or Init the eeprom
      byte *b = &d.cm_okflg; 

      for ( byte i = 0; i < sizeof(d); i++, b++)
      {
        *b = EEPROM.read(i);
      }

      if (d.cm_okflg == 0x55)
      {
        Info.showNumberDec(45);
        return; // nvram is ok
      }

      //Set defaults
      t_nvram defaults;
      d = defaults; 
      Write();
      // Enter diagnostic mode
      Info.showNumberDec(42);
      DiagMode();
  };
  void Write()
  {
      //Write the updated bytes
      char *b = &d.cm_okflg; 

      for ( byte i = 0; i < sizeof(d); i++, b++)
      {
        EEPROM.update(i,*b);
      }
  }
  void DiagMode();

};

// NvRam nv;



void NvRam::DiagMode()
{
/*
  static int p = 0;
  if (! Sw.Ready()) return;
  switch (Sw.Read())
  {
  case 48:
      p++;
      if (p > sizeof(t_nvram))  p = 0;
      break;
  case 49:
      p--;
      if ( p < 0) p = sizeof(t_nvram);
      break;
  }

  Info.showNumberDec( EEPROM.read(p) );
  */
}



/* 
 * The Interrupt routine, every millisecond:
 * 
 * Update shift registers.
 * 
 * Decrease timers
 * 
 * Make the blinking byte blink
 * 
 * Display the CRC low or high part
 * 
 * Limit calls to TM1637 which is time costly
 * 
 */
 bool TTU;
ISR (TIMER1_COMPA_vect) {
   static unsigned int blinkCount;
  
  /*
   * Compiler produces a good code but I wanted to test weird assembler interface !
   */
  register unsigned char ByteToShift asm("r2");
  asm volatile (

    // Instruction        Clock   Description   Phase     Bit Transmitted

    "ldi  r30, lo8(HC595_REGS)       $"   // Z, points to byte array to shift
    "ldi  r31, hi8(HC595_REGS)       $"


    // BYTE 0 load byte from array
    "ld %[bts],  Z+                  $"

    "cbi %[hc595], %[hc595_srclk]    $"   // clk low
    "sbi %[hc595], %[hc595_ser]      $"   // set high
    "sbrs %[bts], 7                  $"   // Skip next instruction if Bit 7 is Set
    "cbi %[hc595], %[hc595_ser]      $"   // set low
    "sbi %[hc595], %[hc595_srclk]    $"   // clk high
    // repeat for remaining bits
    "cbi %[hc595], %[hc595_srclk]    $"   // clk low
    "sbi %[hc595], %[hc595_ser]      $"
    "sbrs %[bts], 6                  $"
    "cbi %[hc595], %[hc595_ser]      $"
    "sbi %[hc595], %[hc595_srclk]    $"   // clk high

    "cbi %[hc595], %[hc595_srclk]    $"   // clk low
    "sbi %[hc595], %[hc595_ser]      $"
    "sbrs %[bts], 5                  $"
    "cbi %[hc595], %[hc595_ser]      $"
    "sbi %[hc595], %[hc595_srclk]    $"   // clk high

    "cbi %[hc595], %[hc595_srclk]    $"   // clk low
    "sbi %[hc595], %[hc595_ser]      $"
    "sbrs %[bts], 4                  $"
    "cbi %[hc595], %[hc595_ser]      $"
    "sbi %[hc595], %[hc595_srclk]    $"   // clk high

    "cbi %[hc595], %[hc595_srclk]    $"   // clk low
    "sbi %[hc595], %[hc595_ser]      $"
    "sbrs %[bts], 3                  $"
    "cbi %[hc595], %[hc595_ser]      $"
    "sbi %[hc595], %[hc595_srclk]    $"   // clk high

    "cbi %[hc595], %[hc595_srclk]    $"   // clk low
    "sbi %[hc595], %[hc595_ser]      $"
    "sbrs %[bts], 2                  $"
    "cbi %[hc595], %[hc595_ser]      $"
    "sbi %[hc595], %[hc595_srclk]    $"   // clk high

    "cbi %[hc595], %[hc595_srclk]    $"   // clk low
    "sbi %[hc595], %[hc595_ser]      $"
    "sbrs %[bts], 1                  $"
    "cbi %[hc595], %[hc595_ser]      $"
    "sbi %[hc595], %[hc595_srclk]    $"   // clk high

    "cbi %[hc595], %[hc595_srclk]    $"   // clk low
    "sbi %[hc595], %[hc595_ser]      $"
    "sbrs %[bts], 0                  $"
    "cbi %[hc595], %[hc595_ser]      $"
    "sbi %[hc595], %[hc595_srclk]    $"   // clk high

    "ld %[bts],  Z+                  $"   // Next byte from the array

    "cbi %[hc595], %[hc595_srclk]    $"   // clk low
    "sbi %[hc595], %[hc595_ser]      $"   // set high
    "sbrs %[bts], 7                  $"   // Skip next instruction if Bit 7 is Set
    "cbi %[hc595], %[hc595_ser]      $"   // set low
    "sbi %[hc595], %[hc595_srclk]    $"   // clk high

    "cbi %[hc595], %[hc595_srclk]    $"   // clk low
    "sbi %[hc595], %[hc595_ser]      $"
    "sbrs %[bts], 6                  $"
    "cbi %[hc595], %[hc595_ser]      $"
    "sbi %[hc595], %[hc595_srclk]    $"   // clk high

    "cbi %[hc595], %[hc595_srclk]    $"   // clk low
    "sbi %[hc595], %[hc595_ser]      $"
    "sbrs %[bts], 5                  $"
    "cbi %[hc595], %[hc595_ser]      $"
    "sbi %[hc595], %[hc595_srclk]    $"   // clk high

    "cbi %[hc595], %[hc595_srclk]    $"   // clk low
    "sbi %[hc595], %[hc595_ser]      $"
    "sbrs %[bts], 4                  $"
    "cbi %[hc595], %[hc595_ser]      $"
    "sbi %[hc595], %[hc595_srclk]    $"   // clk high

    "cbi %[hc595], %[hc595_srclk]    $"   // clk low
    "sbi %[hc595], %[hc595_ser]      $"
    "sbrs %[bts], 3                  $"
    "cbi %[hc595], %[hc595_ser]      $"
    "sbi %[hc595], %[hc595_srclk]    $"   // clk high

    "cbi %[hc595], %[hc595_srclk]    $"   // clk low
    "sbi %[hc595], %[hc595_ser]      $"
    "sbrs %[bts], 2                  $"
    "cbi %[hc595], %[hc595_ser]      $"
    "sbi %[hc595], %[hc595_srclk]    $"   // clk high

    "cbi %[hc595], %[hc595_srclk]    $"   // clk low
    "sbi %[hc595], %[hc595_ser]      $"
    "sbrs %[bts], 1                  $"
    "cbi %[hc595], %[hc595_ser]      $"
    "sbi %[hc595], %[hc595_srclk]    $"   // clk high

    "cbi %[hc595], %[hc595_srclk]    $"   // clk low
    "sbi %[hc595], %[hc595_ser]      $"
    "sbrs %[bts], 0                  $"
    "cbi %[hc595], %[hc595_ser]      $"
    "sbi %[hc595], %[hc595_srclk]    $"   // clk high


    //and move registers to output lactches
    "sbi %[hc595], %[hc595_rclk]    $"   // high
    "cbi %[hc595], %[hc595_rclk]    $"   // low

    :// output operands
    :// input operands
    [bts]          "r" (ByteToShift),
    [hc595_srclk]  "M" (HC595_SRCLK),
    [hc595_ser]    "M" (HC595_SER),
    [hc595_rclk]   "M" (HC595_RCLK),
    [hc595]        "I" _SFR_IO_ADDR(HC595) 
    :// dirty regs
    "r26", "r30", "r31"

  );

  // for reading buttons, maybe simplified ?
  if (countDownRebound) countDownRebound--;
  if (countDown) countDown--;

  // Blinking ~1 second
  // by masking or not the two rightmost digits
  if (!blinkCount--) {
      TTU=true; 
      blinkCount = 400;  // new cycle
      blinkState = !blinkState;
 
      if (! (canBlink && canBlink2) ) {
        blinkState = 0; // force visible anyway
      }

      /* 
       *  CRC 8 digits repeatedly low or high or nothing
       *  just override the displayed digits buffer
       *  with the CRC high, CRC low, blank
       *  It is simpler to recalculate each time than using
       *  another display buffer
       *  The displayCrc is started after reading a Socket
       *  and runs until a keypress/new display
       *  
       *  It is never called in 'blink mode' so no need to
       *  worries about digitsB
      */
      switch (displayCrc) {

        case 10:  // high part
          digits[0] = digitToSegment[0xf & crc>>28];
          digits[1] = digitToSegment[0xf & crc>>24];
          digits[2] = digitToSegment[0xf & crc>>20];
          digits[3] = digitToSegment[0xf & crc>>16];
          displayCrc--;
          break;
        case 6:   // low part
          digits[0] = digitToSegment[0xf & crc>>12];
          digits[1] = digitToSegment[0xf & crc>>8];
          digits[2] = digitToSegment[0xf & crc>>4];
          digits[3] = digitToSegment[0xf & crc];
          displayCrc--;
          break;
        case 1:
          displayCrc = 10;  // restart sequence
        case 0:;            // off, do nothing
          break;
        case 3:   // 'blank' at last to make visual start on CRC
          //Info.setSegments (digitsB[2], 4, 0);
          digits[0] = 0;
          digits[1] = 0;
          digits[2] = 0;
          digits[3] = 0;

        default:
          displayCrc--;  // introduce delays to have time to read the CRC between states.
      }
  }

  // finally decides to update or not the TM1637
  // ideally should not be wakeup by the blinking counter.
  if (TTU) {  //   Serial.print ("x");
    if (blinkState) {  // blink the value, not the address
          Info.setSegments (digitsB, 4, 0);
    } else {
          Info.setSegments (digits, 4, 0);
    }
    TTU = false;
  }
};

/*
 * Some good info here to set up Timers 
 *   http://gammon.com.au/interrupts
 *   https://www.arduinoslovakia.eu/application/timer-calculator
 * 
 */
void setupTimer1() {

  noInterrupts();
  // Clear registers
  TCCR1A = 0;
  TCCR1B = 0;
  TCNT1 = 0;

  // 1000 Hz (8000000/((124+1)*64))
  OCR1A = 124;
  // CTC
  TCCR1B |= (1 << WGM12);
  // Prescaler 64
  TCCR1B |= (1 << CS11) | (1 << CS10);
  // Output Compare Match A Interrupt Enable

#ifdef __AVR_ATmega8__
  TIMSK   |= (1 << OCIE1A);
#else
  TIMSK1  |= (1 << OCIE1A);
#endif
  interrupts();
}

/*
 * 
 * Some debug helper and probably serial interface dialog
 * 
 */
void printHex (byte v) {
  //arduino provided funct is not displaying leading zero, not good.
  char x = (v >> 4) + '0';
  if (x>'9') x += 7;
  Serial.print (x);
  x = (v & 0x0f) + '0';
  if (x>'9') x += 7;
  Serial.print (x);
}

void printBin (byte v) {
  for (byte bit=8; bit; bit--) {
    if ( v & _BV (bit-1) ) Serial.print("1"); else Serial.print("0");
    if (bit==5) Serial.print(".");
  } 
}

void debug() {
  for (promAddress=0; promAddress<32; promAddress++) {
    if (promAddress<10) Serial.print("0");
    Serial.print(promAddress);
    Serial.print(": ");
    printBin (promReadData[promAddress]);
    Serial.print("(");
    printHex (promReadData[promAddress]);
    Serial.print(") : (");
    printHex (promWriteData[promAddress]);
    Serial.print(")");
    printBin (promWriteData[promAddress]);
    if (promReadData[promAddress] != promWriteData[promAddress] ) Serial.print(" <==");
    Serial.println();
  }
}

void beepBad(){
#ifdef __AVR_ATmega8__
  byte irq = TIMSK; // noInterrupts();
  TIMSK = 0;
#else
  byte irq = TIMSK1; // noInterrupts();
  TIMSK1 = 0;
#endif
  tone (buzzer, 80);
  delay (400);
  noTone(buzzer);
#ifdef __AVR_ATmega8__
  TIMSK = irq;      // restore interrupts();
#else
  TIMSK1 = irq;      // restore interrupts();
#endif
}
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
void loop ()
{
  byte testByte, newByte;
  bool pause;

  /* read the W socket */
  setLed(1); 
  setLedW(0);
  setLedR(1);
  clearPromBitSelector;
  PORTD = VPP5V_Q4open;  // power the +pin for reading W socket
  PORTB = 255;            // turn on pull up resistors

  for (promAddress=0; promAddress<32; promAddress++) {
    setPromAddr(promAddress);
    delay(30);  // let at least 2 irq to update shift registers
    promWriteCS0;
    delayMicroseconds(50);
    testByte = PINB;
    promWriteCS1;
    if (testByte != 255) break;  // found a byte with some bits to burn.
  }
  PORTD =  VPP0V_Q4open;
  PORTB = 0; //turn off pull up resistors
  setLedW(1);

  /* check the reading result */
  byte BIT = 255;    //search a bit programmable (eg =0)
  if ( !(testByte & _BV(7)) ) BIT = 7;
  if ( !(testByte & _BV(6)) ) BIT = 6;
  if ( !(testByte & _BV(5)) ) BIT = 5;
  if ( !(testByte & _BV(4)) ) BIT = 4;
  if ( !(testByte & _BV(3)) ) BIT = 3;
  if ( !(testByte & _BV(2)) ) BIT = 2;
  if ( !(testByte & _BV(1)) ) BIT = 1;
  if ( !(testByte & _BV(0)) ) BIT = 0;

  if (BIT == 255) {
    Serial.println("Error, no bit to program in this prom !! ");
    waitRestart(false);
  }
  
  Serial.println();
  Serial.print("Found bit to programm (at ");
  Serial.print(promAddress);
  Serial.print(") ");
  printHex(testByte);
  Serial.println();


  /* We have the bit and addressto to burn  */
  setPromBitSelector(BIT);
  setPromAddr(promAddress);
  delay(30);  // let at least 2 irq to update shift registers

  /* try to burn it while watching keypresses */
  pause = false;
  do {

    wdt_reset();
    if (!pause) {
      Serial.print(".");
  
      doProgTBP18S030();

      /* READING BACK ALWAYS FAIL FOR THE 18S030 */

      // waiting for watchdog  this method read back correctly the new byte
      // but whitout control, will burn the entire prom !
      // while(1);
      
      //read back the byte
      clearPromBitSelector;     //useless
      setPromBitSelector(BIT);  //but was part of
      setPromAddr(promAddress); //tryin readin back, unsuccessfully
      PORTD = VPP5V_Q4open;     // power the +pin for reading W socket
      delay(30);                //let at least 2 irq to update shift registers

      promWriteCS0;
      delayMicroseconds(50);
      newByte = PINB;
      promWriteCS1;
      PORTD = VPP0V_Q4open;
    }

    switch (getButton()) {

    case btRead:
    case btWrite:
    case btMoinsRel:
    case btPlusRel:break;
    case btPlus:
           pause = false;
           setPromBitSelector(BIT);
           setPromAddr(promAddress);
           delay(30);      //let at least 2 irq to update shift registers
           break;
    case btMoins:
           pause = true;
           promWriteDisplay();  
           break;
    case btVal:
    case btValRel:

    default:;
    }

  } while (0 && newByte == testByte); //force out until readback OK !!

  Serial.print("\nBIT PROGRAMMED:");
  printHex(newByte);
  waitRestart(false);  
}

#endif

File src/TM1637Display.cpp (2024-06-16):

 
//  Author: avishorp@gmail.com
//
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
 
extern "C" {
  #include <stdlib.h>
  #include <string.h>
  #include <inttypes.h>
}



#include "TM1637Display.h"
#include <Arduino.h>

#define TM1637_I2C_COMM1    0x40
#define TM1637_I2C_COMM2    0xC0
#define TM1637_I2C_COMM3    0x80

//
//      A
//     ---
//  F |   | B
//     -G-
//  E |   | C
//     ---
//      D

#ifndef __TM1637DISPLAYxxxxxxxx__

TM1637Display::TM1637Display(uint8_t pinClk, uint8_t pinDIO)
{
	// Copy the pin numbers
	m_pinClk = pinClk;
	m_pinDIO = pinDIO;

	// Set the pin direction and default value.
	// Both pins are set as inputs, allowing the pull-up resistors to pull them up
    pinMode(m_pinClk, INPUT);
    pinMode(m_pinDIO,INPUT);
	digitalWrite(m_pinClk, LOW);
	digitalWrite(m_pinDIO, LOW);
}


void TM1637Display::setBrightness(uint8_t brightness, bool on)
{
	m_brightness = (brightness & 0x7) | (on? 0x08 : 0x00);
}

void TM1637Display::setSegments(const uint8_t segments[], uint8_t length, uint8_t pos)
{
    // Write COMM1
	start();
	writeByte(TM1637_I2C_COMM1);
	stop();

	// Write COMM2 + first digit address
	start();
	writeByte(TM1637_I2C_COMM2 + (pos & 0x03));

	// Write the data bytes
	for (uint8_t k=0; k < length; k++)
	  writeByte(segments[k]);

	stop();

	// Write COMM3 + brightness
	start();
	writeByte(TM1637_I2C_COMM3 + (m_brightness & 0x0f));
	stop();
}

void TM1637Display::showNumberDec(int num, bool leading_zero, uint8_t length, uint8_t pos)
{
  showNumberDecEx(num, 0, leading_zero, length, pos);
}

void TM1637Display::showNumberDecEx(int num, uint8_t dots, bool leading_zero,
                                    uint8_t length, uint8_t pos)
{
  uint8_t digits[4];
	const static int divisors[] = { 1, 10, 100, 1000 };
	bool leading = true;

	for(int8_t k = 0; k < 4; k++) {
	    int divisor = divisors[4 - 1 - k];
		int d = num / divisor;
    uint8_t digit = 0;

		if (d == 0) {
		  if (leading_zero || !leading || (k == 3))
		      digit = encodeDigit(d);
	      else
		      digit = 0;
		}
		else {
			digit = encodeDigit(d);
			num -= d * divisor;
			leading = false;
		}
    
    // Add the decimal point/colon to the digit
    digit |= (dots & 0x80); 
    dots <<= 1;
    
    digits[k] = digit;
	}

	setSegments(digits + (4 - length), length, pos);
}


void TM1637Display::bitDelay()
{
  //delayMicroseconds(100);
  for (int i=0; i<80; i++) asm ("nop"); // delay entre 60 et 100 nop
}

void TM1637Display::start()
{
  pinMode(m_pinDIO, OUTPUT);
  bitDelay();
}

void TM1637Display::stop()
{
	pinMode(m_pinDIO, OUTPUT);
	bitDelay();
	pinMode(m_pinClk, INPUT);
	bitDelay();
	pinMode(m_pinDIO, INPUT);
	bitDelay();
}

bool TM1637Display::writeByte(uint8_t b)
{
  uint8_t data = b;

  // 8 Data Bits
  for(uint8_t i = 0; i < 8; i++) {
    // CLK low
    pinMode(m_pinClk, OUTPUT);
    bitDelay();

	// Set data bit
    if (data & 0x01)
      pinMode(m_pinDIO, INPUT);
    else
      pinMode(m_pinDIO, OUTPUT);

    bitDelay();

	// CLK high
    pinMode(m_pinClk, INPUT);
    bitDelay();
    data = data >> 1;
  }

  // Wait for acknowledge
  // CLK to zero
  pinMode(m_pinClk, OUTPUT);
  pinMode(m_pinDIO, INPUT);
  bitDelay();

  // CLK to high
  pinMode(m_pinClk, INPUT);
  bitDelay();
  //uint8_t ack = digitalRead(m_pinDIO);
  //if (ack == 0)
    pinMode(m_pinDIO, OUTPUT);


  bitDelay();
  pinMode(m_pinClk, OUTPUT);
  bitDelay();
  return 0; //ack;
}

uint8_t TM1637Display::encodeDigit(uint8_t digit)
{
	return digitToSegment[digit & 0x0f];
}
#endif

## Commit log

2024-06-16 Add files via upload
    Initial load on github,
    maybe 'bordélique' ;)
    [12mm x 12mm Tactile switch Button.step, DC_Power_Jack_PCB_Mounted_2.1mm.step, G6K-2P-Y-DC5.stp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]
2026-01-12 Good also for TBP18S030
    Need a small hardware change as well as a new programming method.
    The device is for one chip at a time with this pcb. It needs more work
    to have it for both but this is useless for now given the number of
    programming needed !
    [prom-prog.sch]
2026-01-12 fix comment about Elektor
    [prom-prog.sch]

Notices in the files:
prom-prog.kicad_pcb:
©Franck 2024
